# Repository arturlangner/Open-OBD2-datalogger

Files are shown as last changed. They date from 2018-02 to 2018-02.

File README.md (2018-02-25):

# Open OBD2 datalogger
This is an OBD2 datalogger running on an NXP Kinetis E that stores engine data and GPS position to an SD card. It supports CAN and K-line protocols. Visualization is done with HTML5 and JavaScript.

# More information

 - [Project description](https://lb9mg.no/2018/02/25/open-obd-datalogger/)
 - [How to implement OBD2 over CAN](https://lb9mg.no/2017/12/27/reading-obd2-data-without-elm327-part-1-can/)
 - [How to implement OBD2 over K-line](https://lb9mg.no/2018/01/02/reading-obd2-data-without-elm327-part-2-k-line/)

 Contact me if you would like a commercial license.

# Hardware
Complete device (https://lb9mg.no/wp-content/uploads/2018/02/obdlogger_2.jpg)
Closed enclosure (https://lb9mg.no/wp-content/uploads/2018/02/obdlogger_1.jpg)

Schematic (https://lb9mg.no/wp-content/uploads/2018/02/schematic_v0.2.png)

# Demo log
Short trip (https://lb9mg.no/wp-content/uploads/2018/02/obd2_demo_log.png)

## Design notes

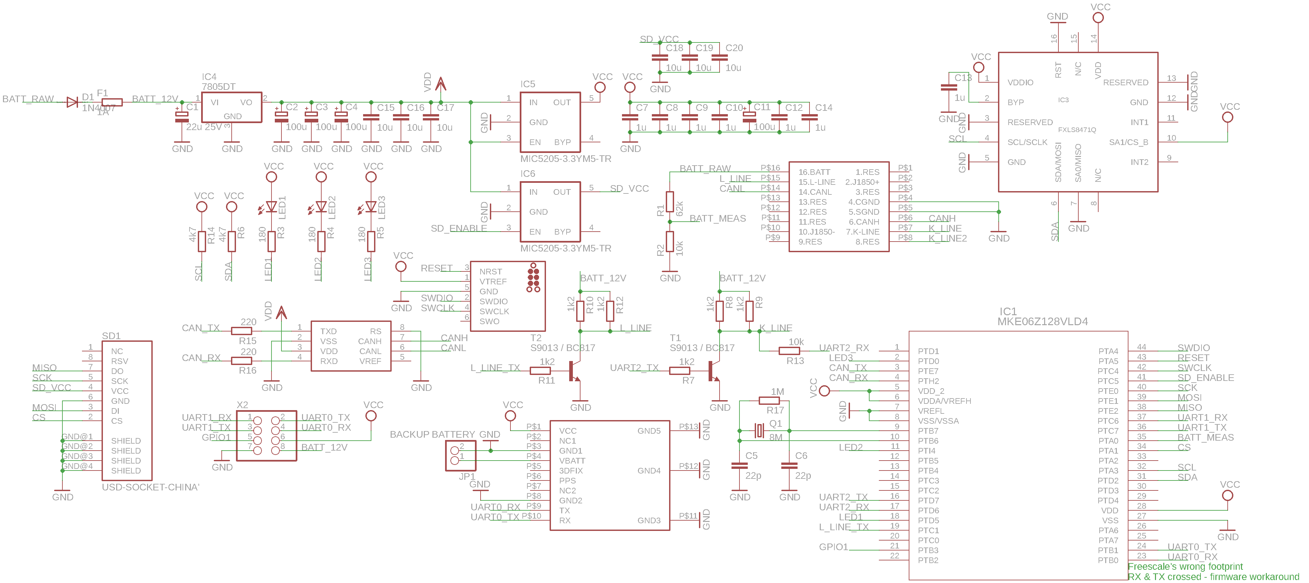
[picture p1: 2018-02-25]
schematic_v0.2.png

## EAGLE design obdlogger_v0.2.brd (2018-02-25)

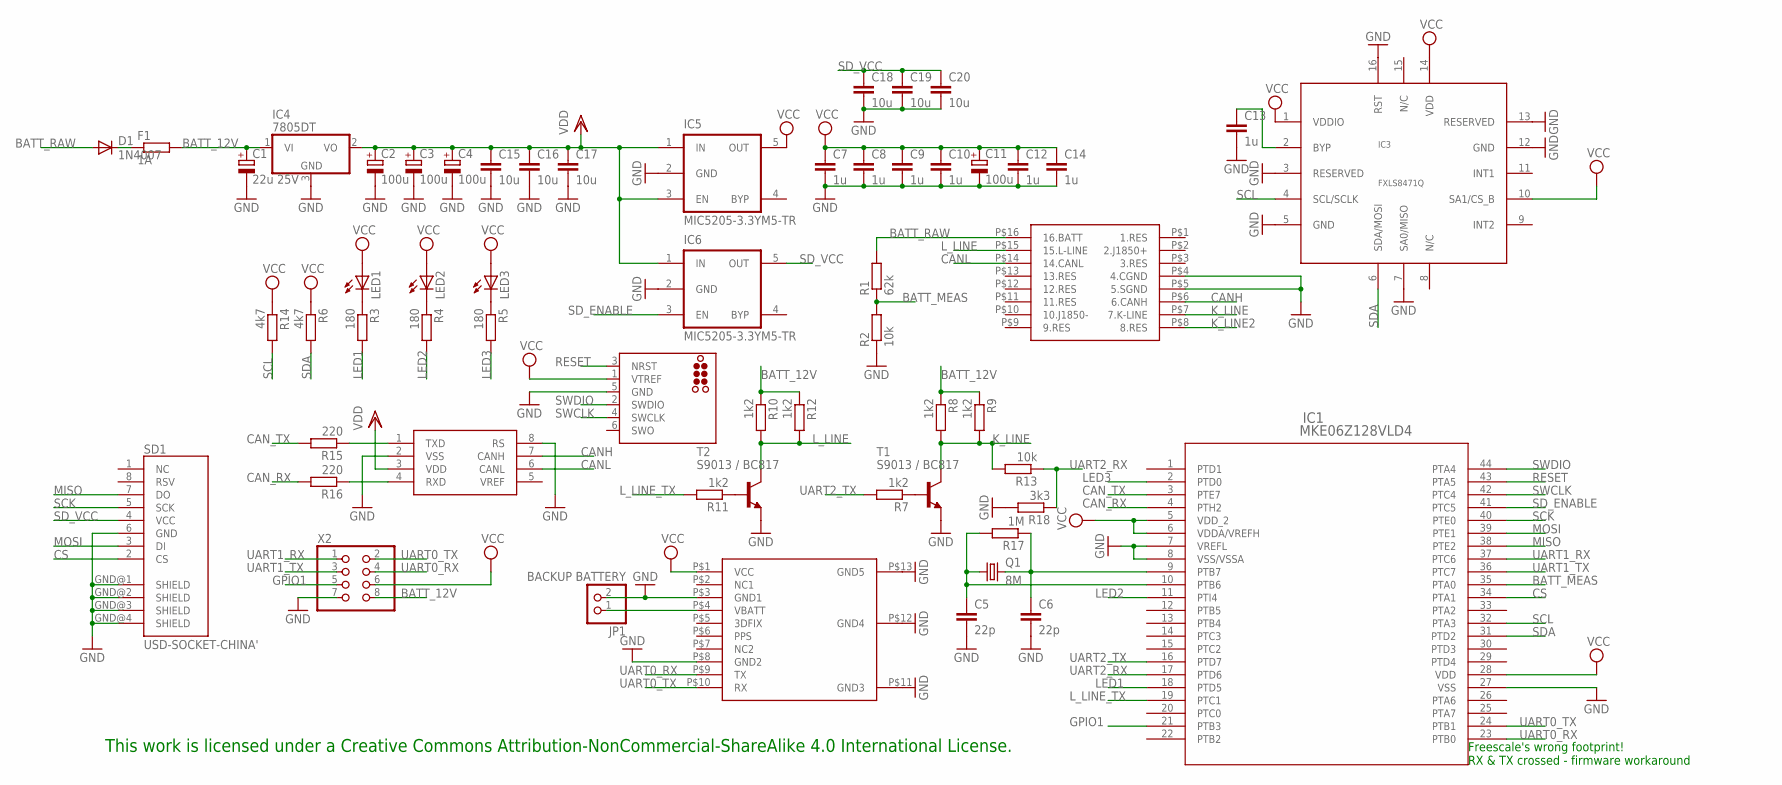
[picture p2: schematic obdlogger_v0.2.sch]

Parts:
C1: 22u 25V; SMC_C
C2, C3, C4, C11: 100u; SMC_B
C5, C6: 22p; C0603K
C7, C8, C9, C10, C12, C13, C14: 1u; C0603K
C15, C16, C17, C18, C19, C20: 10u; C0603K
D1: 1N4007; C1702-05
F1: 1A; R1206
IC1: MKE06Z128VLD4; LQFP-44_10X10X1.4
IC2: MCP2561; SO08
IC3: FXLS8471Q; 16QFN-5/3
IC4: 7805DT; TO252
IC5, IC6: MIC5205-3.3YM5-TR; SOT-23-5
JP1: BACKUP BATTERY; 1X02
LED1, LED2, LED3: LED3MM
Q1: 8M; HC49UP
R1: 62k; R0603
R2, R13: 10k; R0603
R3, R4, R5: 180; R0603
R6, R14: 4k7; R0603
R7, R11: 1k2; R0603
R8, R9, R10, R12: 1k2; M1206
R15, R16: 220; R0603
R17: 1M; R0603
R18: 3k3; R0603
SD1: USD-SOCKET-CHINA'; USD-SOCKET-PP
T1, T2: S9013 / BC817; SOT23-BEC
U$2: SWD-NEEDLE; TC2030-MCP
U$4: PA6C
X1: OBD2-RIGHT-ANGLEPROPER; OBD2-RIGHT-ANGLE-PCB-PROPER
X2: PINHD-2X4; 2X04

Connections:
BATT_12V: C1.+, F1.2, IC4.1 (VI), R8.1, R9.1, R10.1, R12.1, X2.8
BATT_MEAS: IC1.35 (PTA0), R1.1, R2.2
BATT_RAW: D1.A, R1.2, X1.P$16 (16.BATT)
CANH: IC2.7 (CANH), X1.P$6 (6.CANH)
CANL: IC2.6 (CANL), X1.P$14 (14.CANL)
CAN_RX: IC1.4 (PTH2), R16.2
CAN_TX: IC1.3 (PTE7), R15.2
CS: IC1.34 (PTA1), SD1.2 (CS)
GND: C1.-, C2.-, C3.-, C4.-, C5.2, C6.2, C7.2, C8.2, C9.2, C10.2, C11.-, C12.2, C13.2, C14.2, C15.2, C16.2, C17.2, C18.2, C19.2, C20.2, IC1.7 (VREFL), IC1.8 (VSS/VSSA), IC1.27 (VSS), IC2.2 (VSS), IC2.8 (RS), IC3.3 (RESERVED), IC3.5 (GND), IC3.7 (SA0/MISO), IC3.12 (GND), IC3.13 (RESERVED), IC3.16 (RST), IC4.3 (GND), IC5.2 (GND), IC6.2 (GND), JP1.2, R2.1, R18.2, SD1.6 (GND), SD1.GND@1 (SHIELD), SD1.GND@2 (SHIELD), SD1.GND@3 (SHIELD), SD1.GND@4 (SHIELD), T1.E, T2.E, U$2.5 (GND), U$4.P$3 (GND1), U$4.P$8 (GND2), U$4.P$11 (GND3), U$4.P$12 (GND4), U$4.P$13 (GND5), X1.P$4 (4.CGND), X1.P$5 (5.SGND), X2.7
GPIO1: IC1.21 (PTB3), X2.5
K_LINE: R8.2, R9.2, R13.2, T1.C, X1.P$7 (7.K-LINE)
K_LINE2: X1.P$8 (8.RES)
LED1: IC1.18 (PTD5), R3.2
LED2: IC1.11 (PTI4), R4.2
LED3: IC1.2 (PTD0), R5.2
L_LINE: R10.2, R12.2, T2.C, X1.P$15 (15.L-LINE)
L_LINE_TX: IC1.19 (PTC1), R11.2
MISO: IC1.38 (PTE2), SD1.7 (DO)
MOSI: IC1.39 (PTE1), SD1.3 (DI)
unnamed: LED1.K (C), R3.1
unnamed: JP1.1, U$4.P$4 (VBATT)
unnamed: R7.1, T1.B
unnamed: LED2.K (C), R4.1
unnamed: LED3.K (C), R5.1
unnamed: C6.1, IC1.9 (PTB7), Q1.2, R17.1
unnamed: C5.1, IC1.10 (PTB6), Q1.1, R17.2
unnamed: C13.1, IC3.2 (BYP)
unnamed: IC2.1 (TXD), R15.1
unnamed: IC2.4 (RXD), R16.1
unnamed: D1.C, F1.1
unnamed: R11.1, T2.B
RESET: IC1.43 (PTA5), U$2.3 (NRST)
SCK: IC1.40 (PTE0), SD1.5 (SCK)
SCL: IC1.32 (PTA3), IC3.4 (SCL/SCLK), R14.2
SDA: IC1.31 (PTD2), IC3.6 (SDA/MOSI), R6.2
SD_ENABLE: IC1.41 (PTC5), IC6.3 (EN)
SD_VCC: C18.1, C19.1, C20.1, IC6.5 (OUT), SD1.4 (VCC)
SWCLK: IC1.42 (PTC4), U$2.4 (SWCLK)
SWDIO: IC1.44 (PTA4), U$2.2 (SWDIO)
UART0_RX: IC1.23 (PTB0), U$4.P$9 (TX), X2.4
UART0_TX: IC1.24 (PTB1), U$4.P$10 (RX), X2.2
UART1_RX: IC1.37 (PTC6), X2.1
UART1_TX: IC1.36 (PTC7), X2.3
UART2_RX: IC1.17 (PTD6), R13.1, R18.1
UART2_TX: IC1.16 (PTD7), R7.2
VCC: C7.1, C8.1, C9.1, C10.1, C11.+, C12.1, C14.1, IC1.5 (VDD_2), IC1.6 (VDDA/VREFH), IC1.28 (VDD), IC3.1 (VDDIO), IC3.10 (SA1/CS_B), IC3.14 (VDD), IC5.5 (OUT), LED1.A, LED2.A, LED3.A, R6.1, R14.1, U$2.1 (VTREF), U$4.P$1 (VCC), X2.6
VCC_5V: C2.+, C3.+, C4.+, C15.1, C16.1, C17.1, IC2.3 (VDD), IC4.2 (VO), IC5.1 (IN), IC5.3 (EN), IC6.1 (IN)

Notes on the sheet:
Freescale's wrong footprint! RX & TX crossed - firmware workaround
This work is licensed under a Creative Commons Attribution-NonCommercial-ShareAlike 4.0 International License.

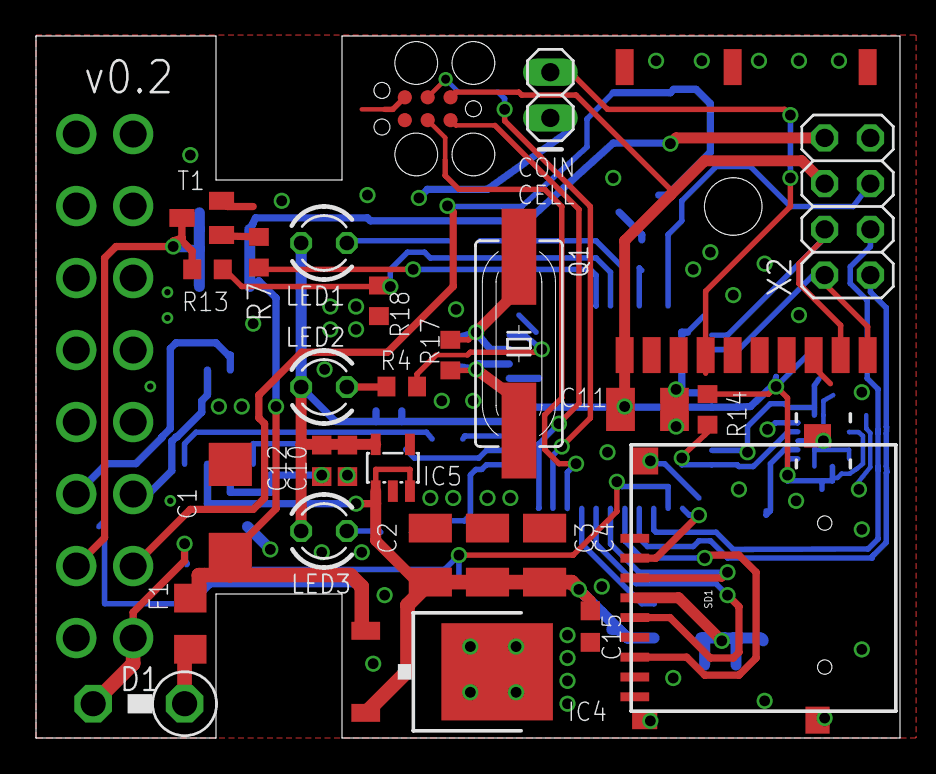
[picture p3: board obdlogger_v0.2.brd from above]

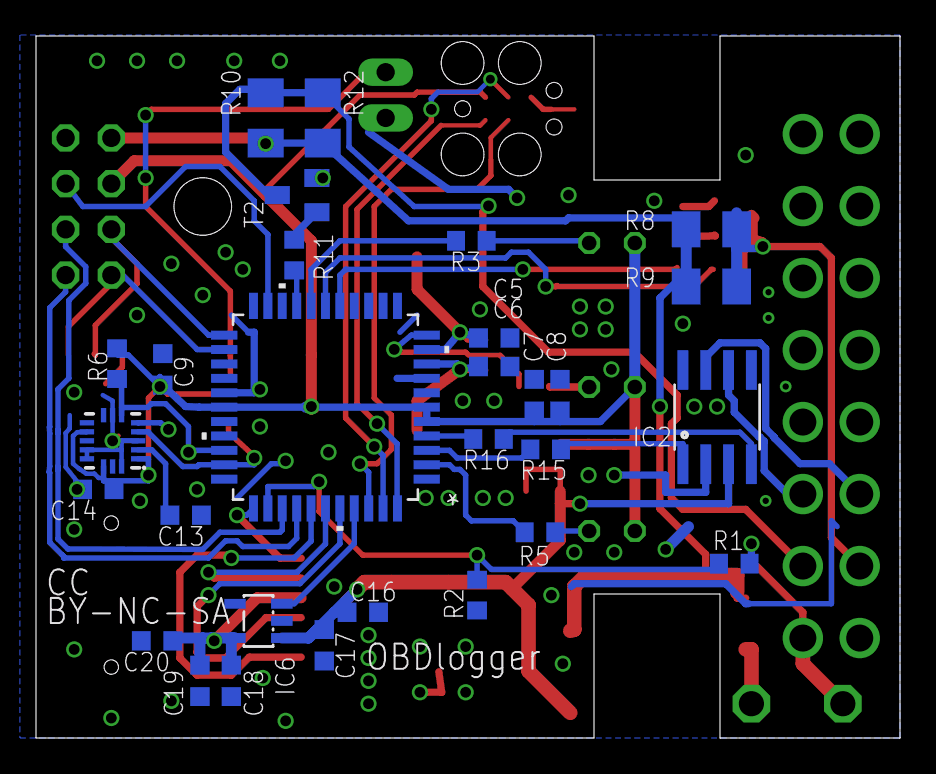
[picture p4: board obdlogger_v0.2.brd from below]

Board: 2 copper layers, 48.0 x 39.0 mm, 58 parts (29 on the bottom side), 46 nets.

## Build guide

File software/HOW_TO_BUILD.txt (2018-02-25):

The firmware consists of the main application and a bootloader.
The bootloader can read new application firmware from SD card
and update the device.

How to build the bootloader:
1. cd bootloader
2. make
3. Binaries will appear in the 'build' directory. Use a
   debugger/programmer to flash bootloader.hex to the device

How to build the application:
1. cd obdlogger
2. make
3. Binaries will appear in the 'build' directory.

main-standalone.hex/bin can be simply flashed by using a JTAG/SWD programmer.

main-bootloadable.bin has to be encrypted and signed by the 'sign_firmware'
utility (go to 'firmware_signing' and type make to build it). 
The encrypted and signed .bin file has to be placed on the SD card in OBDLOG
directory. The device must have the bootloader flashed beforehand.
The bootloader will install the application from that file.

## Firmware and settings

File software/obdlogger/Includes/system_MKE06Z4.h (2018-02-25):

/*
** ###################################################################
**     Compilers:           ARM Compiler
**                          Freescale C/C++ for Embedded ARM
**                          GNU C Compiler
**                          GNU C Compiler - CodeSourcery Sourcery G++
**                          IAR ANSI C/C++ Compiler for ARM
**
**     Reference manual:    MKE06P80M48SF0RM, Rev. 1, Dec 2013
**     Version:             rev. 1.4, 2014-05-28
**     Build:               b140528
**
**     Abstract:
**         Provides a system configuration function and a global variable that
**         contains the system frequency. It configures the device and initializes
**         the oscillator (PLL) that is part of the microcontroller device.
**
**     Copyright (c) 2014 Freescale Semiconductor, Inc.
**     All rights reserved.
**
**     Redistribution and use in source and binary forms, with or without modification,
**     are permitted provided that the following conditions are met:
**
**     o Redistributions of source code must retain the above copyright notice, this list
**       of conditions and the following disclaimer.
**
**     o Redistributions in binary form must reproduce the above copyright notice, this
**       list of conditions and the following disclaimer in the documentation and/or
**       other materials provided with the distribution.
**
**     o Neither the name of Freescale Semiconductor, Inc. nor the names of its
**       contributors may be used to endorse or promote products derived from this
**       software without specific prior written permission.
**
**     THIS SOFTWARE IS PROVIDED BY THE COPYRIGHT HOLDERS AND CONTRIBUTORS "AS IS" AND
**     ANY EXPRESS OR IMPLIED WARRANTIES, INCLUDING, BUT NOT LIMITED TO, THE IMPLIED
**     WARRANTIES OF MERCHANTABILITY AND FITNESS FOR A PARTICULAR PURPOSE ARE
**     DISCLAIMED. IN NO EVENT SHALL THE COPYRIGHT HOLDER OR CONTRIBUTORS BE LIABLE FOR
**     ANY DIRECT, INDIRECT, INCIDENTAL, SPECIAL, EXEMPLARY, OR CONSEQUENTIAL DAMAGES
**     (INCLUDING, BUT NOT LIMITED TO, PROCUREMENT OF SUBSTITUTE GOODS OR SERVICES;
**     LOSS OF USE, DATA, OR PROFITS; OR BUSINESS INTERRUPTION) HOWEVER CAUSED AND ON
**     ANY THEORY OF LIABILITY, WHETHER IN CONTRACT, STRICT LIABILITY, OR TORT
**     (INCLUDING NEGLIGENCE OR OTHERWISE) ARISING IN ANY WAY OUT OF THE USE OF THIS
**     SOFTWARE, EVEN IF ADVISED OF THE POSSIBILITY OF SUCH DAMAGE.
**
**     http:                 www.freescale.com
**     mail:                 support@freescale.com
**
**     Revisions:
**     - rev. 1.0 (2013-07-30)
**         Initial version.
**     - rev. 1.1 (2013-10-29)
**         Definition of BITBAND macros updated to support peripherals with 32-bit acces disabled.
**     - rev. 1.2 (2013-10-30)
**         Update according to reference manual rev. 1.
**     - rev. 1.3 (2014-01-10)
**         CAN module: corrected address of TSIDR1 register.
**         CAN module: corrected name of MSCAN_TDLR bit DLC to TDLC.
**         FTM0 module: added access macro for EXTTRIG register.
**         NVIC module: registers access macros improved.
**         SCB module: unused bits removed, mask, shift macros improved.
**         Defines of interrupt vectors aligned to RM.
**     - rev. 1.4 (2014-05-28)
**         The declaration of clock configurations has been moved to separate header file system_MKE02Z2.h
**         Module access macro {module}_BASES replaced by {module}_BASE_PTRS.
**         I2C module: renamed status register S to S1 to match RM naming.
**
** ###################################################################
*/

/*!
 * @file MKE06Z4
 * @version 1.4
 * @date 2014-05-28
 * @brief Device specific configuration file for MKE06Z4 (header file)
 *
 * Provides a system configuration function and a global variable that contains
 * the system frequency. It configures the device and initializes the oscillator
 * (PLL) that is part of the microcontroller device.
 */

#ifndef SYSTEM_MKE06Z4_H_
#define SYSTEM_MKE06Z4_H_                        /**< Symbol preventing repeated inclusion */

#ifdef __cplusplus
extern "C" {
#endif

#include <stdint.h>


#define DISABLE_WDOG    1

#ifndef CLOCK_SETUP
  #define CLOCK_SETUP   1
#endif
/* Predefined clock setups
   0 ... Internal Clock Source (ICS) in FLL Engaged Internal (FEI) mode
         Default  part configuration.
         Reference clock source for ICS module is the slow internal clock source 32.768kHz
         Core clock = 20.97MHz, BusClock = 20.97MHz
   1 ... Internal Clock Source (ICS) in FLL Engaged External (FEE) mode
         Maximum achievable clock frequency configuration.
         Reference clock source for ICS module is an external 8MHz crystal
         Core clock = 40MHz, BusClock = 20MHz
   2 ... Internal Clock Source (ICS) in Bypassed Low Power Internal (FBILP) mode
         Core clock/Bus clock derived directly from an  internal clock 32.769kHz with no multiplication
         The clock settings is ready for Very Low Power Run mode.
         Core clock = 32.769kHz, BusClock = 32.769kHz
   3 ... Internal Clock Source (ICS) in Bypassed Low Power External (BLPE) mode
         Core clock/Bus clock derived directly from the external 8MHz crystal
         The clock settings is ready for Very Low Power Run mode.
         Core clock = 8MHz, BusClock = 8MHz
*/

/*----------------------------------------------------------------------------
  Define clock source values
 *----------------------------------------------------------------------------*/
#if (CLOCK_SETUP == 0)
    #define CPU_XTAL_CLK_HZ                 8000000u /* Value of the external crystal or oscillator clock frequency in Hz */
    #define CPU_INT_CLK_HZ                  32768u   /* Value of the internal oscillator clock frequency in Hz  */
    #define DEFAULT_SYSTEM_CLOCK            20971520u /* Default System clock value */
	#error "DEFAULT_BUS_CLOCK not defined!"
#elif (CLOCK_SETUP == 1)
    #define CPU_XTAL_CLK_HZ                 8000000u /* Value of the external crystal or oscillator clock frequency in Hz */
    #define CPU_INT_CLK_HZ                  32768u   /* Value of the internal oscillator clock frequency in Hz  */
    #define DEFAULT_SYSTEM_CLOCK            40000000u /* Default System clock value */
	#define DEFAULT_BUS_CLOCK               20000000u
#elif (CLOCK_SETUP == 2)
    #define CPU_XTAL_CLK_HZ                 8000000u /* Value of the external crystal or oscillator clock frequency in Hz */
    #define CPU_INT_CLK_HZ                  32768u   /* Value of the internal oscillator clock frequency in Hz  */
    #define DEFAULT_SYSTEM_CLOCK            32768u   /* Default System clock value */
	#error "DEFAULT_BUS_CLOCK not defined!"
#elif (CLOCK_SETUP == 3)
    #define CPU_XTAL_CLK_HZ                 8000000u /* Value of the external crystal or oscillator clock frequency in Hz */
    #define CPU_INT_CLK_HZ                  32768u   /* Value of the internal oscillator clock frequency in Hz  */
    #define DEFAULT_SYSTEM_CLOCK            8000000u /* Default System clock value */
	#error "DEFAULT_BUS_CLOCK not defined!"
#endif /* (CLOCK_SETUP == 4) */


/**
 * @brief System clock frequency (core clock)
 *
 * The system clock frequency supplied to the SysTick timer and the processor
 * core clock. This variable can be used by the user application to setup the
 * SysTick timer or configure other parameters. It may also be used by debugger to
 * query the frequency of the debug timer or configure the trace clock speed
 * SystemCoreClock is initialized with a correct predefined value.
 */
extern uint32_t SystemCoreClock;

/**
 * @brief Setup the microcontroller system.
 *
 * Typically this function configures the oscillator (PLL) that is part of the
 * microcontroller device. For systems with variable clock speed it also updates
 * the variable SystemCoreClock. SystemInit is called from startup_device file.
 */
void SystemInit (void);

/**
 * @brief Updates the SystemCoreClock variable.
 *
 * It must be called whenever the core clock is changed during program
 * execution. SystemCoreClockUpdate() evaluates the clock register settings and calculates
 * the current core clock.
 */
void SystemCoreClockUpdate (void);

#ifdef __cplusplus
}
#endif

#endif  /* #if !defined(SYSTEM_MKE06Z4_H_) */

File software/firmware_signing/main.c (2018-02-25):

/*
Open OBD2 datalogger
Copyright (C) 2018 Artur Langner

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
You should have received a copy of the GNU General Public License
along with this program.  If not, see <http://www.gnu.org/licenses/>.
*/
#include <stdio.h>
#include <sys/random.h>
#include <string.h>
#include "../common/cifra/aes.h"
#include "../common/cifra/modes.h"
#include "../common/keys.h"
/* File format:
 * encrypted payload
 * CMAC(encrypted payload)
 *
 * The encrypted payload contains:
 * 16 bytes - random nonce
 * XX bytes - binary firmware image
 *  4 bytes - CRC32 of the binary firmware image, little-endian
 */

static uint8_t input_buffer[128*1024]; //maximum image size must be smaller anyway because bootloader occupies ~20KB
static uint8_t output_buffer[128*1024]; //maximum image size must be smaller anyway because bootloader occupies ~20KB

#define debug_dump_buffer(len, buffer, msg) do { \
		printf("%d:%s: %s len %d", __LINE__, __func__, msg, len);\
		for (uint32_t iiiii = 0; iiiii < len; iiiii++){ \
			if (iiiii % 16 == 0){ printf("\n"); }\
			printf("%02X", ((uint8_t*)buffer)[iiiii]);\
		} \
		printf("\n");\
} while (0)


static uint32_t crc32(const void *buf, size_t size);

int main(int argc, char **argv){
	if (argc != 3){
		printf("Usage: ./sign firmware_file.bin signed_firmware.bin\n");
		return 1;
	}

	FILE *input_file_handle;
	input_file_handle = fopen(argv[1],"rb");
	if (!input_file_handle){
		printf("Can't open input file\n");
		return 2;
	}

	FILE *output_file_handle;
	output_file_handle = fopen(argv[2],"wb");
	if (!output_file_handle){
		printf("Can't open output file\n");
		return 2;
	}

	cf_cbc cbc_context;
	cf_aes_context aes_context;

	cf_aes_init(&aes_context, encryption_key, AES_BLOCKSZ);
	cf_cbc_init(&cbc_context, &cf_aes, &aes_context, encryption_iv);

	uint8_t nonce[AES_BLOCKSZ];
	int random_length = getrandom(nonce, sizeof(nonce), 0);
	if (random_length != sizeof(nonce)){
		printf("getrandom() failure?\n");
		return 4;
	}

//	memset(nonce, 0, sizeof(nonce)); #warning "Nonce is zero!"

	cf_cbc_encrypt(&cbc_context, nonce, output_buffer, 1); //encrypt nonce (one block)

	int bytes_written = 0;

	int application_size = fread(input_buffer, 1, sizeof(input_buffer), input_file_handle);
	printf("input file size %d bytes\n", application_size);

	//add CRC32 at the end of the image
	uint32_t crc = crc32(input_buffer, application_size);
	printf("Image CRC is %04X\n", crc);
	memcpy(input_buffer+application_size, &crc, sizeof(crc));
	application_size += sizeof(crc);

	//round up to nearest block size
	int blocks_to_encrypt = (application_size / AES_BLOCKSZ);
	int remainder = application_size % AES_BLOCKSZ;
	if (remainder){
		//application_size += (AES_BLOCKSZ - remainder);
		blocks_to_encrypt++; //round up to nearest AES block boundary
	}
	blocks_to_encrypt++; //add 1 block for nonce placed before the image

	printf("blocks to encrypt %d (%d bytes)\n", blocks_to_encrypt, blocks_to_encrypt*AES_BLOCKSZ);

	cf_cbc_encrypt(&cbc_context, input_buffer, output_buffer+AES_BLOCKSZ/*nonce comes first*/, blocks_to_encrypt);

	uint8_t signature[AES_BLOCKSZ];
	cf_aes_init(&aes_context, authentication_key, AES_BLOCKSZ);

	cf_cmac cmac_context;
	cf_cmac_init(&cmac_context, &cf_aes, &aes_context);

	cf_cmac_sign(&cmac_context, output_buffer, (blocks_to_encrypt)*AES_BLOCKSZ, signature);

	bytes_written = fwrite(output_buffer, 1, (blocks_to_encrypt)*AES_BLOCKSZ, output_file_handle);
	printf("written %d bytes\n", bytes_written);

	bytes_written = fwrite(signature, 1, sizeof(signature), output_file_handle);
	printf("written %d bytes\n", bytes_written);

	fclose(output_file_handle);

	return 0;
}

// https://opensource.apple.com/source/xnu/xnu-792.21.3/bsd/libkern/crc32.c
static uint32_t crc32(const void *buf, size_t size){
	static uint32_t crc32_tab[] = {
			0x00000000, 0x77073096, 0xee0e612c, 0x990951ba, 0x076dc419, 0x706af48f,
			0xe963a535, 0x9e6495a3,	0x0edb8832, 0x79dcb8a4, 0xe0d5e91e, 0x97d2d988,
			0x09b64c2b, 0x7eb17cbd, 0xe7b82d07, 0x90bf1d91, 0x1db71064, 0x6ab020f2,
			0xf3b97148, 0x84be41de,	0x1adad47d, 0x6ddde4eb, 0xf4d4b551, 0x83d385c7,
			0x136c9856, 0x646ba8c0, 0xfd62f97a, 0x8a65c9ec,	0x14015c4f, 0x63066cd9,
			0xfa0f3d63, 0x8d080df5,	0x3b6e20c8, 0x4c69105e, 0xd56041e4, 0xa2677172,
			0x3c03e4d1, 0x4b04d447, 0xd20d85fd, 0xa50ab56b,	0x35b5a8fa, 0x42b2986c,
			0xdbbbc9d6, 0xacbcf940,	0x32d86ce3, 0x45df5c75, 0xdcd60dcf, 0xabd13d59,
			0x26d930ac, 0x51de003a, 0xc8d75180, 0xbfd06116, 0x21b4f4b5, 0x56b3c423,
			0xcfba9599, 0xb8bda50f, 0x2802b89e, 0x5f058808, 0xc60cd9b2, 0xb10be924,
			0x2f6f7c87, 0x58684c11, 0xc1611dab, 0xb6662d3d,	0x76dc4190, 0x01db7106,
			0x98d220bc, 0xefd5102a, 0x71b18589, 0x06b6b51f, 0x9fbfe4a5, 0xe8b8d433,
			0x7807c9a2, 0x0f00f934, 0x9609a88e, 0xe10e9818, 0x7f6a0dbb, 0x086d3d2d,
			0x91646c97, 0xe6635c01, 0x6b6b51f4, 0x1c6c6162, 0x856530d8, 0xf262004e,
			0x6c0695ed, 0x1b01a57b, 0x8208f4c1, 0xf50fc457, 0x65b0d9c6, 0x12b7e950,
			0x8bbeb8ea, 0xfcb9887c, 0x62dd1ddf, 0x15da2d49, 0x8cd37cf3, 0xfbd44c65,
			0x4db26158, 0x3ab551ce, 0xa3bc0074, 0xd4bb30e2, 0x4adfa541, 0x3dd895d7,
			0xa4d1c46d, 0xd3d6f4fb, 0x4369e96a, 0x346ed9fc, 0xad678846, 0xda60b8d0,
			0x44042d73, 0x33031de5, 0xaa0a4c5f, 0xdd0d7cc9, 0x5005713c, 0x270241aa,
			0xbe0b1010, 0xc90c2086, 0x5768b525, 0x206f85b3, 0xb966d409, 0xce61e49f,
			0x5edef90e, 0x29d9c998, 0xb0d09822, 0xc7d7a8b4, 0x59b33d17, 0x2eb40d81,
			0xb7bd5c3b, 0xc0ba6cad, 0xedb88320, 0x9abfb3b6, 0x03b6e20c, 0x74b1d29a,
			0xead54739, 0x9dd277af, 0x04db2615, 0x73dc1683, 0xe3630b12, 0x94643b84,
			0x0d6d6a3e, 0x7a6a5aa8, 0xe40ecf0b, 0x9309ff9d, 0x0a00ae27, 0x7d079eb1,
			0xf00f9344, 0x8708a3d2, 0x1e01f268, 0x6906c2fe, 0xf762575d, 0x806567cb,
			0x196c3671, 0x6e6b06e7, 0xfed41b76, 0x89d32be0, 0x10da7a5a, 0x67dd4acc,
			0xf9b9df6f, 0x8ebeeff9, 0x17b7be43, 0x60b08ed5, 0xd6d6a3e8, 0xa1d1937e,
			0x38d8c2c4, 0x4fdff252, 0xd1bb67f1, 0xa6bc5767, 0x3fb506dd, 0x48b2364b,
			0xd80d2bda, 0xaf0a1b4c, 0x36034af6, 0x41047a60, 0xdf60efc3, 0xa867df55,
			0x316e8eef, 0x4669be79, 0xcb61b38c, 0xbc66831a, 0x256fd2a0, 0x5268e236,
			0xcc0c7795, 0xbb0b4703, 0x220216b9, 0x5505262f, 0xc5ba3bbe, 0xb2bd0b28,
			0x2bb45a92, 0x5cb36a04, 0xc2d7ffa7, 0xb5d0cf31, 0x2cd99e8b, 0x5bdeae1d,
			0x9b64c2b0, 0xec63f226, 0x756aa39c, 0x026d930a, 0x9c0906a9, 0xeb0e363f,
			0x72076785, 0x05005713, 0x95bf4a82, 0xe2b87a14, 0x7bb12bae, 0x0cb61b38,
			0x92d28e9b, 0xe5d5be0d, 0x7cdcefb7, 0x0bdbdf21, 0x86d3d2d4, 0xf1d4e242,
			0x68ddb3f8, 0x1fda836e, 0x81be16cd, 0xf6b9265b, 0x6fb077e1, 0x18b74777,
			0x88085ae6, 0xff0f6a70, 0x66063bca, 0x11010b5c, 0x8f659eff, 0xf862ae69,
			0x616bffd3, 0x166ccf45, 0xa00ae278, 0xd70dd2ee, 0x4e048354, 0x3903b3c2,
			0xa7672661, 0xd06016f7, 0x4969474d, 0x3e6e77db, 0xaed16a4a, 0xd9d65adc,
			0x40df0b66, 0x37d83bf0, 0xa9bcae53, 0xdebb9ec5, 0x47b2cf7f, 0x30b5ffe9,
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
	};

	uint32_t crc = 0;
	const uint8_t *p;

	p = buf;
	crc = crc ^ ~0U;

	while (size--)
		crc = crc32_tab[(crc ^ *p++) & 0xFF] ^ (crc >> 8);

	return crc ^ ~0U;
}

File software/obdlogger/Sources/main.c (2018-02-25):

/*
Open OBD2 datalogger
Copyright (C) 2018 Artur Langner

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
You should have received a copy of the GNU General Public License
along with this program.  If not, see <http://www.gnu.org/licenses/>.
*/
#include "acquisition_task.h"
#include "application_tasks.h"
#include "crash_handler.h"
#include <debug.h>
#include "MKE06Z4.h"
#include <FreeRTOS/include/FreeRTOS.h>
#include <FreeRTOS/include/queue.h>
#include <FreeRTOS/include/task.h>
#include <FreeRTOS/include/semphr.h>
#include "SEGGER/SEGGER_RTT.h"
#include "storage_task.h"
#include "pins.h"
#include "timer.h"
#include "watchdog.h"

void vApplicationIdleHook(void);
void vApplicationStackOverflowHook(TaskHandle_t xTask, signed char *pcTaskName);

int main(void){

	SEGGER_RTT_Init();
	SEGGER_RTT_printf(0, "hello\n");
#ifdef USE_SYSTEMVIEW
	SEGGER_SYSVIEW_Conf();
#endif

	crash_handler_init();

	LED_INIT();

	watchdog_init();

    debug_init();

    timer_init();

    xTaskCreateStatic(storage_task,            //task function
    				  "storage task",            //task logical name
					  STACK_BYTES_TO_WORDS(STACK_SIZE_STORAGE_TASK),  //size of stack
					  NULL,                  //no extra parameters
					  1,                     //priority (0 is lowest - idle task)
					  STACK_STORAGE_TASK,          //stack pointer
					  &storage_task_handle);       //pointer to StaticTask_t

    xTaskCreateStatic(acquisition_task,            //task function
    				  "acquisition task",            //task logical name
					  STACK_BYTES_TO_WORDS(STACK_SIZE_ACQUISITION_TASK),  //size of stack
					  NULL,                  //no extra parameters
					  1,                     //priority (0 is lowest - idle task)
					  STACK_ACQUISITION_TASK,          //stack pointer
					  &acquisition_task_handle);       //pointer to StaticTask_t

    vTaskStartScheduler(); //never returns, enables interrupts

    return 0;
}

void vApplicationIdleHook(void){
	watchdog_kick();
	//if there is nothing to do - CPU core sleep
	__WFI();
}

void vApplicationStackOverflowHook(TaskHandle_t xTask __attribute__((unused)), signed char *pcTaskName){
	snprintf(GLOBAL_news_from_the_grave, sizeof(GLOBAL_news_from_the_grave), "!stk<%s>", pcTaskName);
	__DSB();
	asm("bkpt #1");
}

#if configSUPPORT_STATIC_ALLOCATION
/* static memory allocation for the IDLE task */
static StaticTask_t xIdleTaskTCBBuffer;
static StackType_t xIdleStack[configMINIMAL_STACK_SIZE]; //StackType_t is uint32_t!

void vApplicationGetIdleTaskMemory(StaticTask_t **ppxIdleTaskTCBBuffer, StackType_t **ppxIdleTaskStackBuffer, uint32_t *pulIdleTaskStackSize);

void vApplicationGetIdleTaskMemory(StaticTask_t **ppxIdleTaskTCBBuffer, StackType_t **ppxIdleTaskStackBuffer, uint32_t *pulIdleTaskStackSize) {
  *ppxIdleTaskTCBBuffer = &xIdleTaskTCBBuffer;
  *ppxIdleTaskStackBuffer = xIdleStack;
  *pulIdleTaskStackSize = STACK_BYTES_TO_WORDS(sizeof(xIdleStack));
}
#endif

#if configSUPPORT_STATIC_ALLOCATION && configUSE_TIMERS
static StaticTask_t xTimerTaskTCBBuffer;
static StackType_t xTimerStack[256/sizeof(StackType_t)];

void vApplicationGetTimerTaskMemory(StaticTask_t **ppxTimerTaskTCBBuffer, StackType_t **ppxTimerTaskStackBuffer, uint32_t *pulTimerTaskStackSize);
/* If static allocation is supported then the application must provide the
   following callback function - which enables the application to optionally
   provide the memory that will be used by the timer task as the task's stack
   and TCB. */
void vApplicationGetTimerTaskMemory(StaticTask_t **ppxTimerTaskTCBBuffer, StackType_t **ppxTimerTaskStackBuffer, uint32_t *pulTimerTaskStackSize) {
  *ppxTimerTaskTCBBuffer = &xTimerTaskTCBBuffer;
  *ppxTimerTaskStackBuffer = &xTimerStack[0];
  *pulTimerTaskStackSize = sizeof(xTimerStack);
}
#endif

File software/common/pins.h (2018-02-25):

#pragma once
#include <MKE06Z4.h>

#ifdef BOARD_EVK

#define LED_INIT() do {\
		GPIOB_PDDR |= PORT_PUE1_PTGPE5_MASK | PORT_PUE1_PTGPE6_MASK | PORT_PUE1_PTGPE7_MASK;/*set as outputs*/\
		GPIOB_PSOR = PORT_PUE1_PTGPE5_MASK | PORT_PUE1_PTGPE6_MASK | PORT_PUE1_PTGPE7_MASK;/*all leds off*/\
		} while (0)

#define LED1_ON()    GPIOB_PCOR = PORT_PUE1_PTGPE5_MASK
#define LED1_OFF()   GPIOB_PSOR = PORT_PUE1_PTGPE5_MASK
#define LED2_ON()  GPIOB_PCOR = PORT_PUE1_PTGPE6_MASK
#define LED2_OFF() GPIOB_PSOR = PORT_PUE1_PTGPE6_MASK
#define LED3_ON()   GPIOB_PCOR = PORT_PUE1_PTGPE7_MASK
#define LED3_OFF()  GPIOB_PSOR = PORT_PUE1_PTGPE7_MASK

#define SPI0_PINS_INIT() do { \
		GPIOB_PDDR |= PORT_PUE1_PTEPE3_MASK; /*PTE3 is CS GPIO*/ \
		SIM_PINSEL0 |= SIM_PINSEL_SPI0PS_MASK; /*map pins: SCK PTE0, MOSI PTE1, MISO PTE2*/ \
		} while (0)

#define SPI0_CS_HIGH()  GPIOB_PSOR = PORT_PUE1_PTEPE3_MASK
#define SPI0_CS_LOW()   GPIOB_PCOR = PORT_PUE1_PTEPE3_MASK

#define SD_POWER_ON() //not used by the development kit, card is always on
#define SD_POWER_OFF()
#warning "Build uses EVK pins!!!"
#else
//LED1 PTD5
//LED2 PTI4
//LED3 PTD0
#define LED_INIT() do {\
		GPIOA_PDDR |= PORT_PUE0_PTDPE5_MASK/*LED1*/ | PORT_PUE0_PTDPE0_MASK/*LED3*/ ; /*set as outputs*/\
		GPIOA_PSOR = PORT_PUE0_PTDPE5_MASK/*LED1*/ | PORT_PUE0_PTDPE0_MASK/*LED3*/ ; /*all leds off*/\
		GPIOC_PDDR |= PORT_PUE2_PTIPE4_MASK/*LED2*/ ; /*set as outputs*/\
		GPIOC_PSOR = PORT_PUE2_PTIPE4_MASK/*LED2*/ ; /*all leds off*/\
		} while (0)

#define LED1_ON()    GPIOA_PCOR = PORT_PUE0_PTDPE5_MASK
#define LED1_OFF()   GPIOA_PSOR = PORT_PUE0_PTDPE5_MASK
#define LED2_ON()  GPIOC_PCOR = PORT_PUE2_PTIPE4_MASK
#define LED2_OFF() GPIOC_PSOR = PORT_PUE2_PTIPE4_MASK
#define LED3_ON()   GPIOA_PCOR = PORT_PUE0_PTDPE0_MASK
#define LED3_OFF()  GPIOA_PSOR = PORT_PUE0_PTDPE0_MASK

#define SPI0_PINS_INIT() do { \
		GPIOA_PDDR |= PORT_PUE0_PTAPE1_MASK; /*PTA1 is CS GPIO*/ \
		GPIOA_PSOR = PORT_PUE0_PTAPE1_MASK; /*CS HIGH*/ \
		SIM_PINSEL0 |= SIM_PINSEL_SPI0PS_MASK; /*map pins: SCK PTE0, MOSI PTE1, MISO PTE2*/ \
		} while (0)

#define SPI0_PINS_DEINIT() do { /*all pins GPIO - low to reduce power consumption*/ \
		GPIOA_PDDR |= PORT_PUE0_PTAPE1_MASK; /*PTA1 is CS GPIO*/ \
		GPIOA_PCOR = PORT_PUE0_PTAPE1_MASK; /*CS HIGH*/ \
		GPIOB_PDDR |= PORT_PUE1_PTEPE0_MASK | PORT_PUE1_PTEPE1_MASK | PORT_PUE1_PTEPE2_MASK; /*SCK, MOSI, MISO*/ \
		GPIOB_PCOR |= PORT_PUE1_PTEPE0_MASK | PORT_PUE1_PTEPE1_MASK | PORT_PUE1_PTEPE2_MASK; /*all low*/ \
		} while (0)

#define SPI0_CS_HIGH()  GPIOA_PSOR = PORT_PUE0_PTAPE1_MASK
#define SPI0_CS_LOW()   GPIOA_PCOR = PORT_PUE0_PTAPE1_MASK

#define SD_POWER_ON() do { \
		GPIOA_PDDR |= PORT_PUE0_PTCPE5_MASK; /*PTC5 is LDO enable line*/ \
		GPIOA_PSOR = PORT_PUE0_PTCPE5_MASK; /*line high, enable LDO*/ \
		PORT_PUE1 = PORT_PUE1_PTEPE2_MASK; /*MISO pullup*/ \
		PORT_PUE0 = PORT_PUE0_PTAPE1_MASK; /*CS pullup*/ \
		} while (0)

#define SD_POWER_OFF() GPIOA_PCOR |= PORT_PUE0_PTCPE5_MASK /*line low, disable LDO*/


#define K_LINE_LOW()  GPIOA_PSOR = PORT_PUE0_PTDPE7_MASK //line drives NPN transistor so GPIO high is K-Line low
#define K_LINE_HIGH() GPIOA_PCOR = PORT_PUE0_PTDPE7_MASK //line drives NPN transistor so GPIO low is K-Line high

#define K_LINE_INIT() do { \
		GPIOA_PDDR |= PORT_PUE0_PTDPE7_MASK/*K-Line TX - output*/; \
		K_LINE_HIGH(); \
		} while (0)

#define K_LINE_UART UART2
#define K_LINE_UART_IRQ_HANDLER UART2_IRQHandler
#define K_LINE_UART_IRQn UART2_IRQn
#define K_LINE_UART_CLOCK_ENABLE_MASK SIM_SCGC_UART2_MASK

#define L_LINE_INIT() do { \
		GPIOA_PDDR |= PORT_PUE0_PTCPE1_MASK/*L-Line - output*/; \
		L_LINE_HIGH(); \
		} while (0)

#define L_LINE_LOW()  GPIOA_PSOR = PORT_PUE0_PTCPE1_MASK //line drives NPN transistor so GPIO high is L-Line low
#define L_LINE_HIGH() GPIOA_PCOR = PORT_PUE0_PTCPE1_MASK //line drives NPN transistor so GPIO low is L-Line high

#define UART_BITBANG_TX_INIT() do { \
		GPIOA_PDDR |= PORT_PUE0_PTBPE0_MASK/*PTB0*/; \
		UART_BITBANG_TX_HIGH(); \
		} while (0)

#define UART_BITBANG_TX_HIGH() GPIOA_PSOR = PORT_PUE0_PTBPE0_MASK
#define UART_BITBANG_TX_LOW() GPIOA_PCOR = PORT_PUE0_PTBPE0_MASK

#endif

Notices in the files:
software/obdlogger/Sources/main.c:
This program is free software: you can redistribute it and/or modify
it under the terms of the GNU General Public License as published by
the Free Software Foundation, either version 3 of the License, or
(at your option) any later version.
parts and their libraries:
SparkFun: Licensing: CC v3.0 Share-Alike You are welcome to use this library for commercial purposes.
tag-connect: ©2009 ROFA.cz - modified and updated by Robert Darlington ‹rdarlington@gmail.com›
